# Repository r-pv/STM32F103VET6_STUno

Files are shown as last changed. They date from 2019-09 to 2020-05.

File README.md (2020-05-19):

# STM32F103VET6 STUno

An ST development board based on the STM32F103VET6/STM32F103VE (Clock: 72MHz, Flash: 512Kb, Ram:64Kb) MCU (the LQFP-100 version of the famous Blue Pill) compatible with STM32Duino (Arduino).

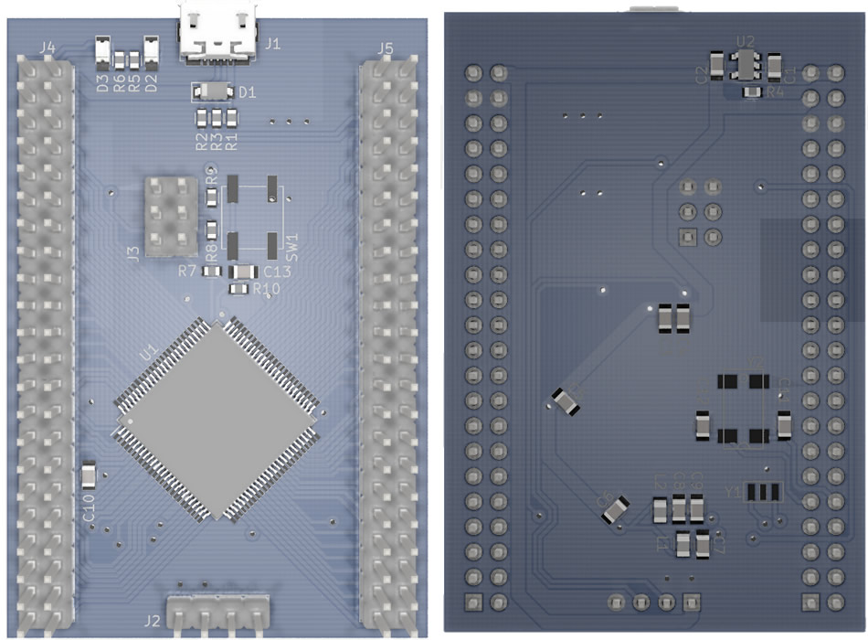
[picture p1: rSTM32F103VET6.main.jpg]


Pinout:

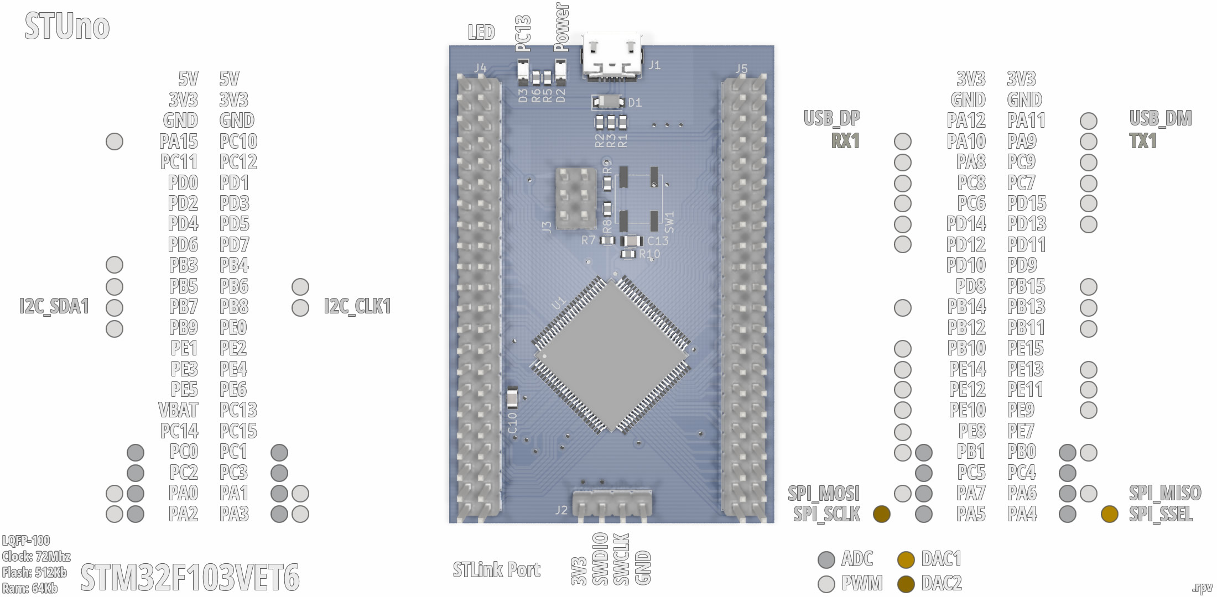
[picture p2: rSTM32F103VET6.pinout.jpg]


## Files and Folders description

- **RBOARD_F103VET6** it's the variant board for the STM32 Arduino Core.
- **rSTM32F103VET6** it's the KiCAD 5.1.2 project.
- **rSTM32F103VET6.schematic.pdf** the schematic.

## Install

**Update:** Since STCore version **1.9.0** most of the F103XXXX boards (including this) are already supported, so there is no need to install anything.

- This requires the [STM32 core for arduino](https://github.com/stm32duino/Arduino_Core_STM32/), the ST original.
- I used this [guide to add the board](https://github.com/stm32duino/wiki/wiki/Add-a-new-variant-(board)), you can check it or continue with my suggestions to install the new board.
- Copy the **"RBOARD_F103VET6"** folder to the Arduino **"variants"** folder, in win7 is located at: **c:\Users\\<USERNAME\>\AppData\Local\Arduino15\packages\STM32\hardware\stm32\1.8.0\variants**
- Edit the **"boards.txt"** file, in win7 is located at a lever up than the "variants" folder, search for the **Generic F1** board line and add the lines to leave it as I show you next:

```
GenF1.menu.pnum.Generic_F103RET6=Generic F103RET6 (Blue Button)
GenF1.menu.pnum.Generic_F103RET6.upload.maximum_size=524288
GenF1.menu.pnum.Generic_F103RET6.upload.maximum_data_size=65536
GenF1.menu.pnum.Generic_F103RET6.build.board=GENERIC_F103RET6
GenF1.menu.pnum.Generic_F103RET6.build.product_line=STM32F103xE
GenF1.menu.pnum.Generic_F103RET6.build.variant=Generic_F103Rx

# Generic STM32F103VET6 STUno
GenF1.menu.pnum.RBOARD_F103VET6=STM32F103VET6 STUno
GenF1.menu.pnum.RBOARD_F103VET6.upload.maximum_size=524288
GenF1.menu.pnum.RBOARD_F103VET6.upload.maximum_data_size=65536
GenF1.menu.pnum.RBOARD_F103VET6.build.board=RBOARD_F103VET6
GenF1.menu.pnum.RBOARD_F103VET6.build.product_line=STM32F103xE
GenF1.menu.pnum.RBOARD_F103VET6.build.variant=RBOARD_F103VET6
```
(add after the _"# Generic STM32F103Rx boards (Blue button)"_ section).

That's all.

So on the arduino IDE, on the **boards** menu pick the option _"Generic STM32F1 series"_ and the **board part number:** suboption pick the _"STM32F103VET6 STUno"_ option.

## The real board

**Front**

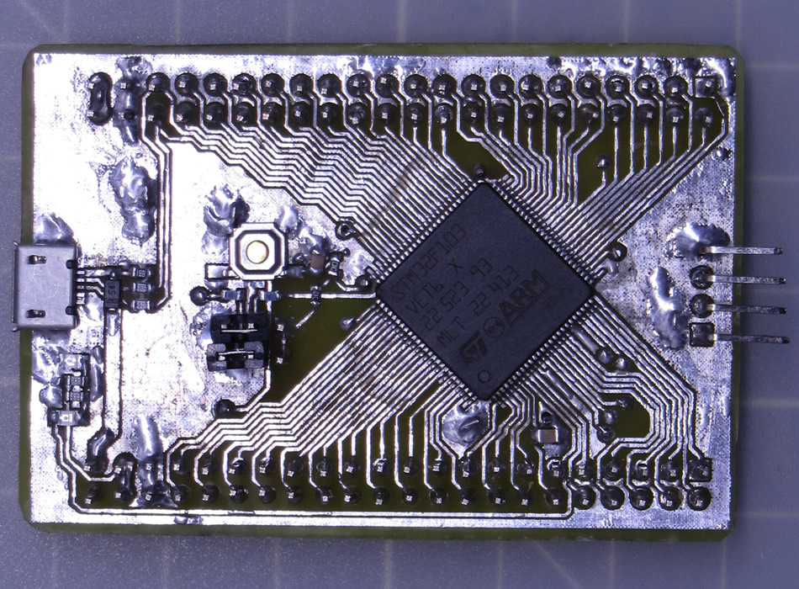
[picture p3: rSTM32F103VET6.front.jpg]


**Back**

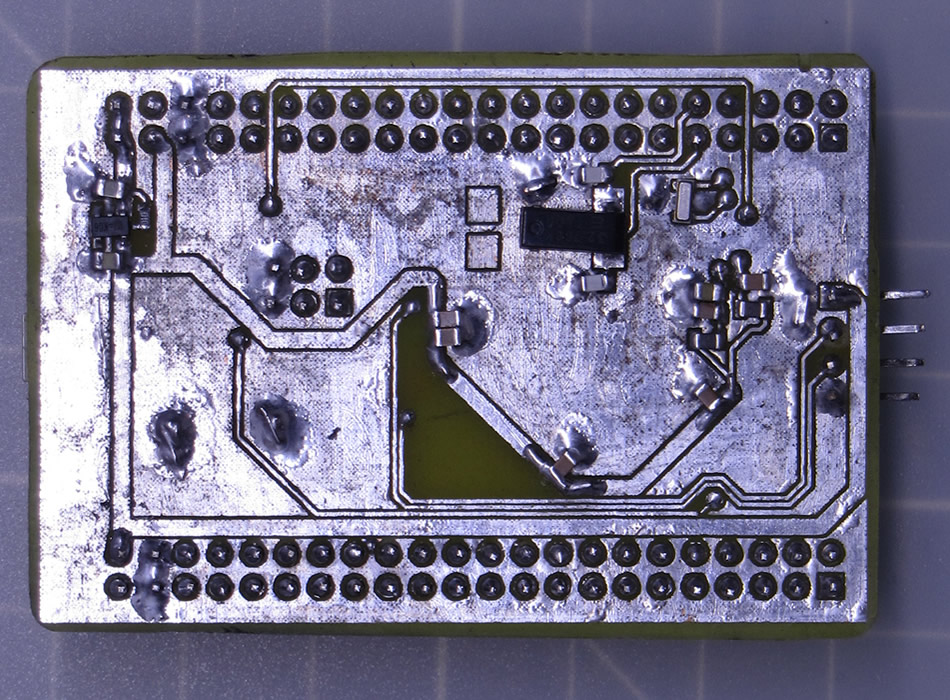
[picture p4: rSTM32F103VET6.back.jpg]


_*The footprint for the second crystal (Y2) was wrong on this board but it's already corrected on the KiCAD files._

## Running some tests

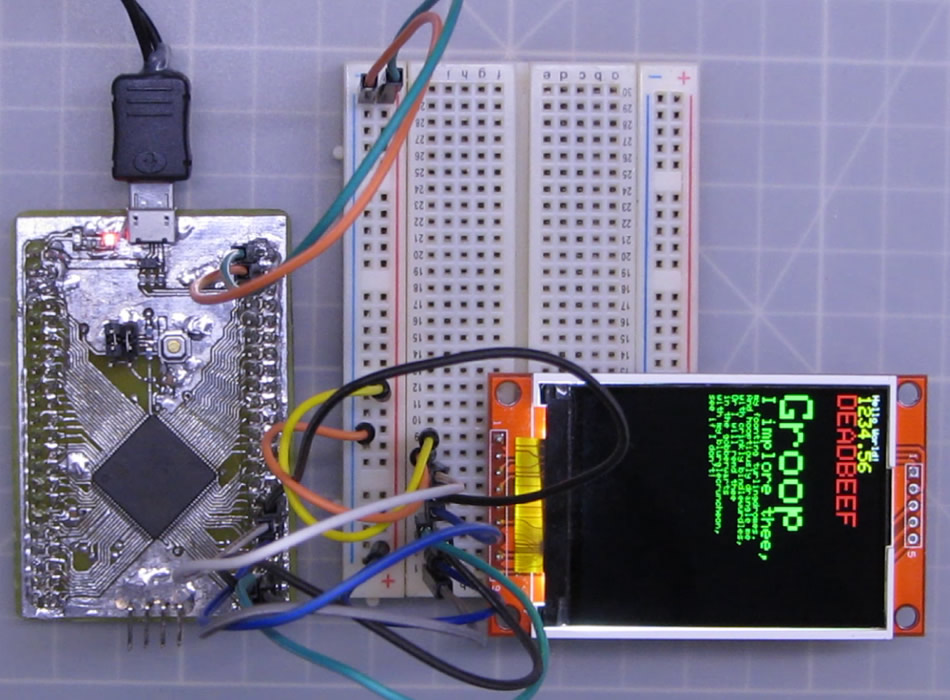
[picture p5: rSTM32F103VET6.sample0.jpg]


The **STUno** running the Adafruit ILI9341 library over hardware SPI.

_Video in progress..._

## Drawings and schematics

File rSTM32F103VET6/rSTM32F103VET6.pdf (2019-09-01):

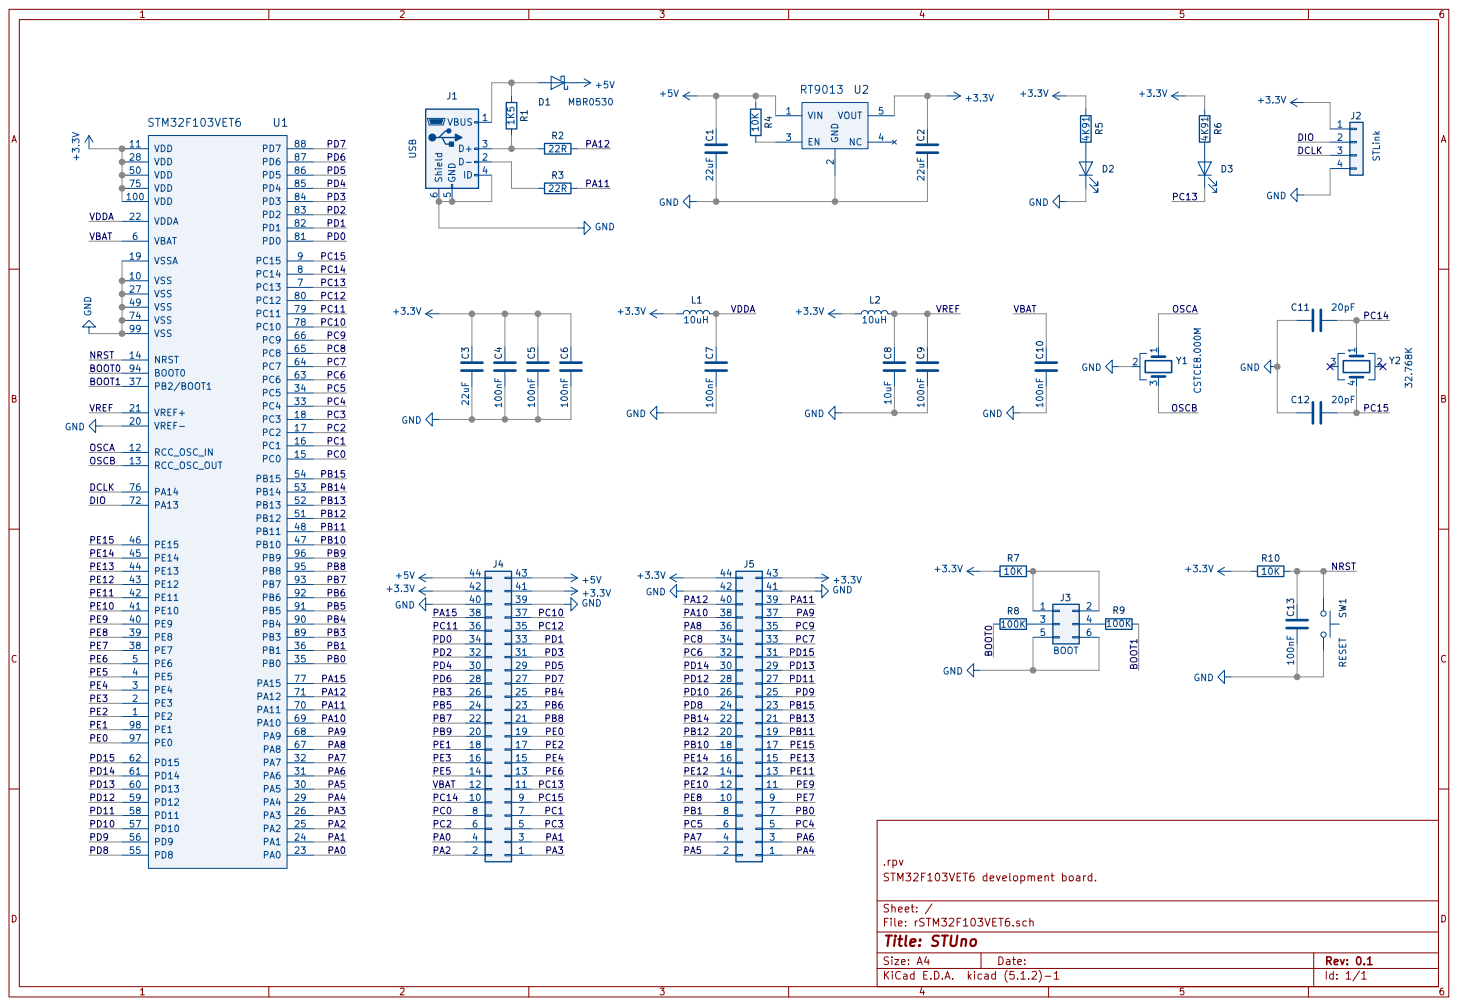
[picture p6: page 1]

File: rSTM32F103VET6.sch Sheet: / STM32F103VET6 development board.

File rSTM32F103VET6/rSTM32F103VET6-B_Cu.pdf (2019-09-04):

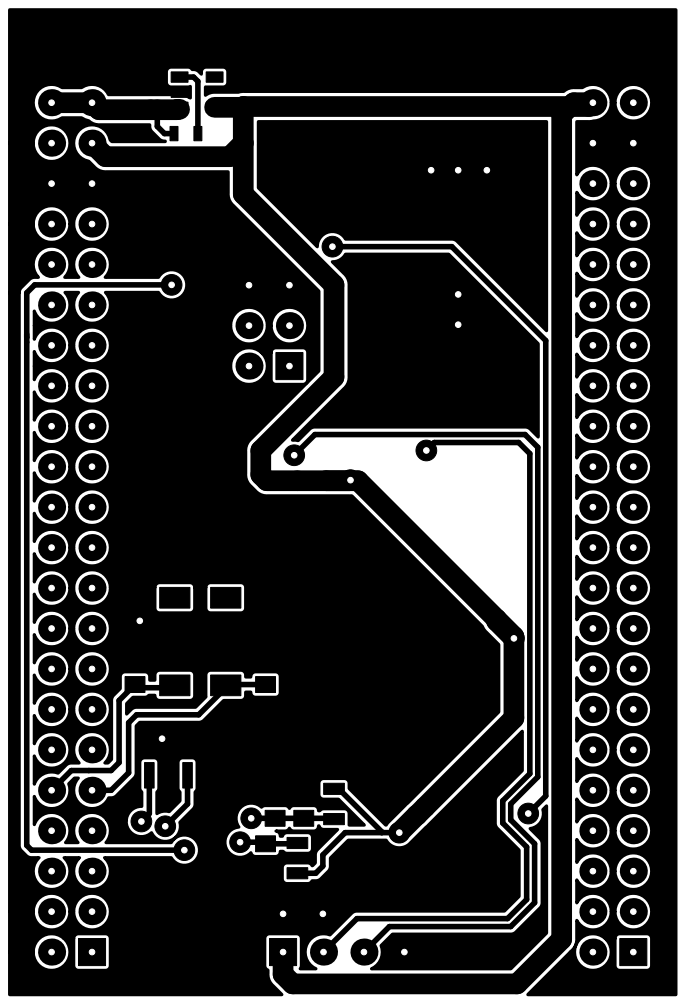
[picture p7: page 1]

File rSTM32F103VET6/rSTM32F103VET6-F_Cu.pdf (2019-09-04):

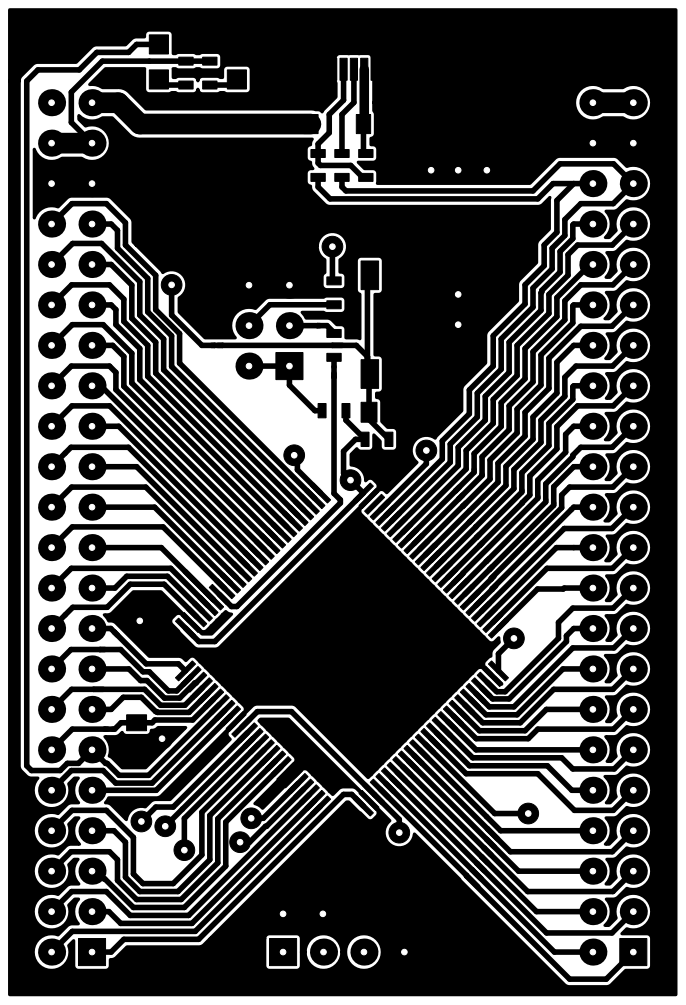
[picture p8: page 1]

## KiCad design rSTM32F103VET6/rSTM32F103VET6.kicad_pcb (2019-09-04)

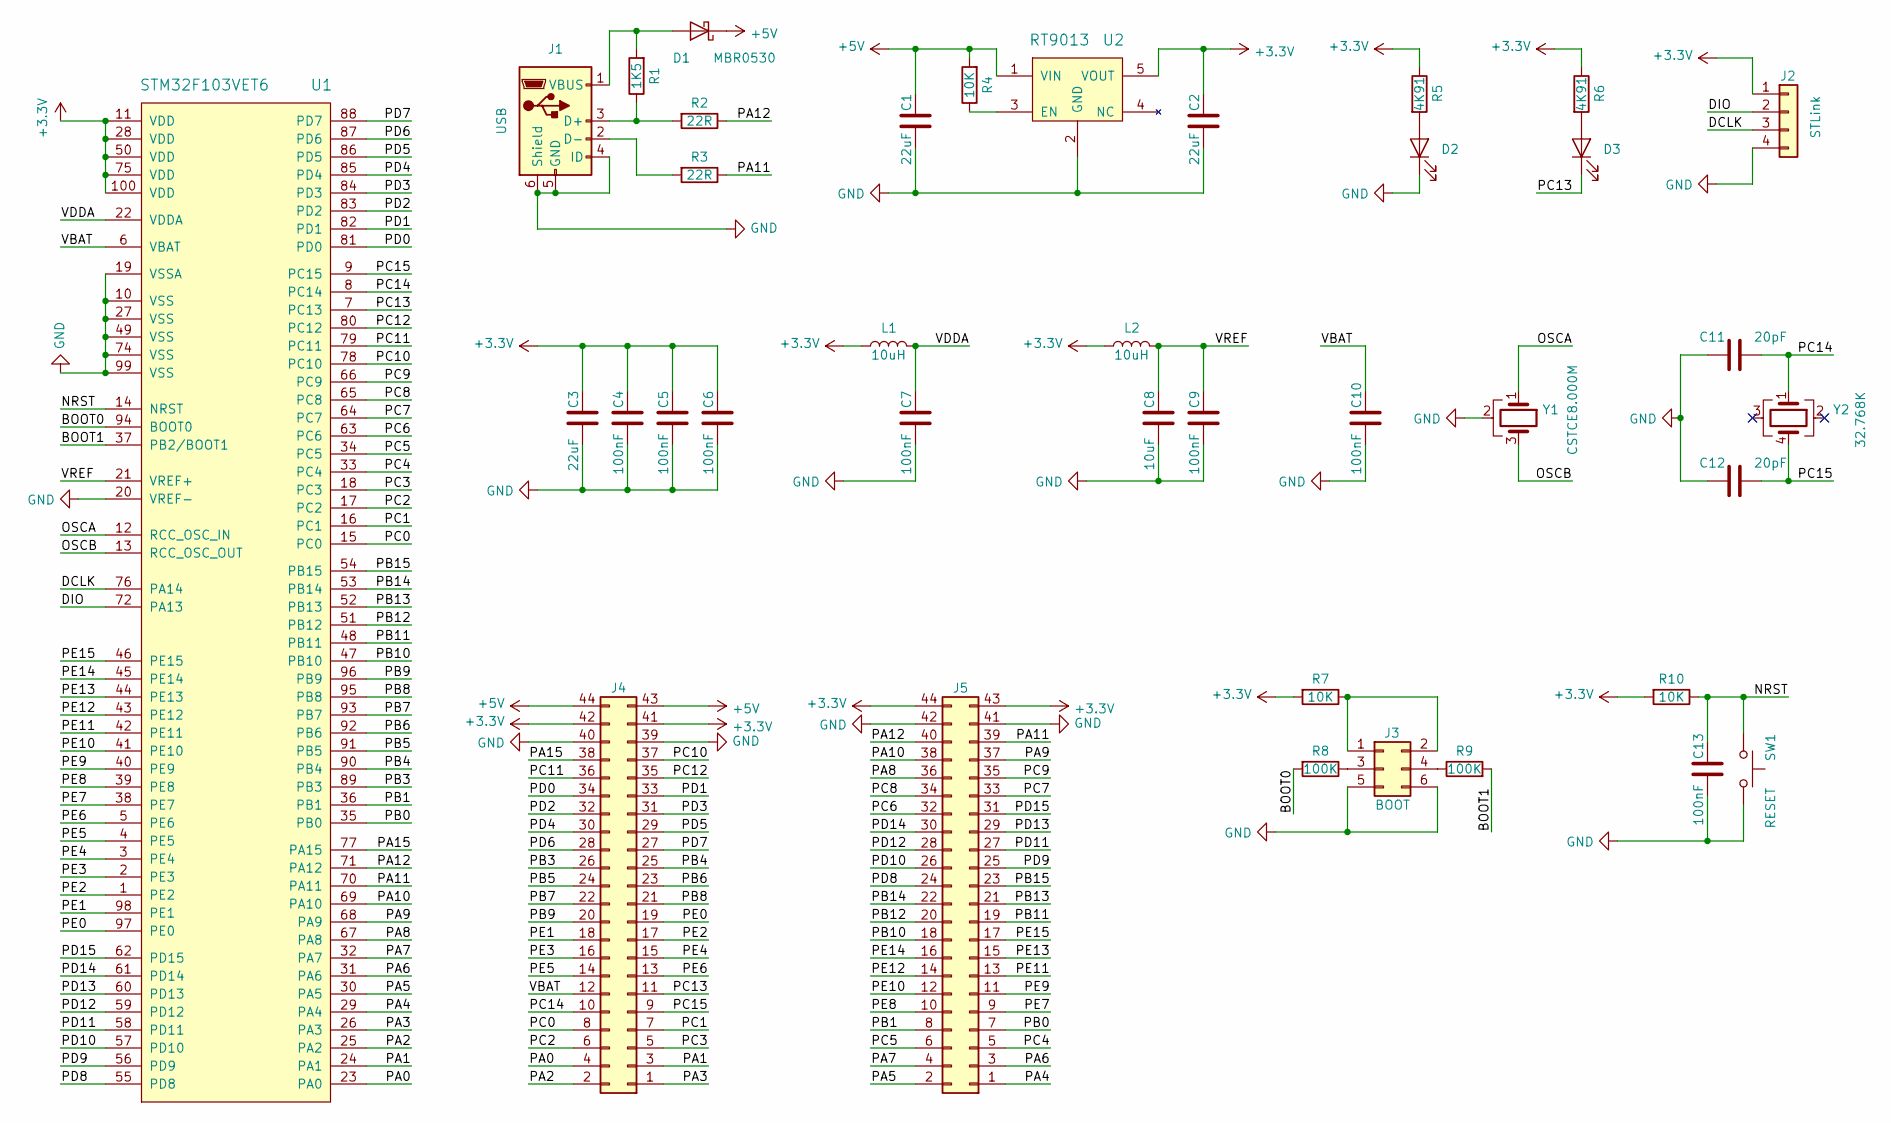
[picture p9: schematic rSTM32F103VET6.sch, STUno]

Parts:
C1, C2, C3: 22uF; C_0805
C4, C5, C6, C7, C9, C10, C13: 100nF; C_0805
C8: 10uF; C_0805
C11, C12: 20pF; C_0805
D1: MBR0530; D_SOD-123
D2, D3: LED; LED_0805
J1: USB; USB_Micro-B_Molex_47346-0001
J2: STLink; Pin_Header_Straight_1x04_Pitch2.54mm
J3: BOOT; Pin_Header_Straight_2x03_Pitch2.54mm
J4, J5: Pin_Header_Straight_2x22_Pitch2.54mm
L1, L2: 10uH; L_0805
R1: 1K5; R_0603
R2, R3: 22R; R_0603
R4, R7, R10: 10K; R_0603
R5, R6: 4K91; R_0603
R8, R9: 100K; R_0603
SW1: RESET; Switch_SMD_5.2x6.4_reset
U1: STM32F103VET6; LQFP-100_14x14mm_Pitch0.5mm
U2: RT9013; SOT-23-5
Y1: CSTCE8.000M; Crystal_CSTCE_3pin_3.2x1.3
Y2: 32.768K; Crystal_4pin_SMD_2.5x4.6

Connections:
+3V3: C2.1, C3.1, C4.1, C5.1, C6.1, J2.1, J4.41, J4.42, J5.43, J5.44, L1.1, L2.1, R5.1, R6.1, R7.2, R10.2, U1.11 (VDD), U1.28 (VDD), U1.50 (VDD), U1.75 (VDD), U1.100 (VDD), U2.5 (VOUT)
+5V: C1.1, D1.1 (K), J4.43, J4.44, R4.2, U2.1 (VIN)
/BOOT0: R8.2, U1.94 (BOOT0)
/BOOT1: R9.2, U1.37 (PB2/BOOT1)
/DCLK: J2.3, U1.76 (PA14)
/DIO: J2.2, U1.72 (PA13)
/NRST: C13.1, R10.1, SW1.1, U1.14 (NRST)
/OSCA: U1.12 (RCC_OSC_IN), Y1.1
/OSCB: U1.13 (RCC_OSC_OUT), Y1.3
/PA0: J4.4, U1.23 (PA0)
/PA1: J4.3, U1.24 (PA1)
/PA2: J4.2, U1.25 (PA2)
/PA3: J4.1, U1.26 (PA3)
/PA4: J5.1, U1.29 (PA4)
/PA5: J5.2, U1.30 (PA5)
/PA6: J5.3, U1.31 (PA6)
/PA7: J5.4, U1.32 (PA7)
/PA8: J5.36, U1.67 (PA8)
/PA9: J5.37, U1.68 (PA9)
/PA10: J5.38, U1.69 (PA10)
/PA11: J5.39, R3.1, U1.70 (PA11)
/PA12: J5.40, R2.1, U1.71 (PA12)
/PA15: J4.38, U1.77 (PA15)
/PB0: J5.7, U1.35 (PB0)
/PB1: J5.8, U1.36 (PB1)
/PB3: J4.26, U1.89 (PB3)
/PB4: J4.25, U1.90 (PB4)
/PB5: J4.24, U1.91 (PB5)
/PB6: J4.23, U1.92 (PB6)
/PB7: J4.22, U1.93 (PB7)
/PB8: J4.21, U1.95 (PB8)
/PB9: J4.20, U1.96 (PB9)
/PB10: J5.18, U1.47 (PB10)
/PB11: J5.19, U1.48 (PB11)
/PB12: J5.20, U1.51 (PB12)
/PB13: J5.21, U1.52 (PB13)
/PB14: J5.22, U1.53 (PB14)
/PB15: J5.23, U1.54 (PB15)
/PC0: J4.8, U1.15 (PC0)
/PC1: J4.7, U1.16 (PC1)
/PC2: J4.6, U1.17 (PC2)
/PC3: J4.5, U1.18 (PC3)
/PC4: J5.5, U1.33 (PC4)
/PC5: J5.6, U1.34 (PC5)
/PC6: J5.32, U1.63 (PC6)
/PC7: J5.33, U1.64 (PC7)
/PC8: J5.34, U1.65 (PC8)
/PC9: J5.35, U1.66 (PC9)
/PC10: J4.37, U1.78 (PC10)
/PC11: J4.36, U1.79 (PC11)
/PC12: J4.35, U1.80 (PC12)
/PC13: D3.1 (K), J4.11, U1.7 (PC13)
/PC14: C11.1, J4.10, U1.8 (PC14), Y2.1
/PC15: C12.1, J4.9, U1.9 (PC15), Y2.4
/PD0: J4.34, U1.81 (PD0)
/PD1: J4.33, U1.82 (PD1)
/PD2: J4.32, U1.83 (PD2)
/PD3: J4.31, U1.84 (PD3)
/PD4: J4.30, U1.85 (PD4)
/PD5: J4.29, U1.86 (PD5)
/PD6: J4.28, U1.87 (PD6)
/PD7: J4.27, U1.88 (PD7)
/PD8: J5.24, U1.55 (PD8)
/PD9: J5.25, U1.56 (PD9)
/PD10: J5.26, U1.57 (PD10)
/PD11: J5.27, U1.58 (PD11)
/PD12: J5.28, U1.59 (PD12)
/PD13: J5.29, U1.60 (PD13)
/PD14: J5.30, U1.61 (PD14)
/PD15: J5.31, U1.62 (PD15)
/PE0: J4.19, U1.97 (PE0)
/PE1: J4.18, U1.98 (PE1)
/PE2: J4.17, U1.1 (PE2)
/PE3: J4.16, U1.2 (PE3)
/PE4: J4.15, U1.3 (PE4)
/PE5: J4.14, U1.4 (PE5)
/PE6: J4.13, U1.5 (PE6)
/PE7: J5.9, U1.38 (PE7)
/PE8: J5.10, U1.39 (PE8)
/PE9: J5.11, U1.40 (PE9)
/PE10: J5.12, U1.41 (PE10)
/PE11: J5.13, U1.42 (PE11)
/PE12: J5.14, U1.43 (PE12)
/PE13: J5.15, U1.44 (PE13)
/PE14: J5.16, U1.45 (PE14)
/PE15: J5.17, U1.46 (PE15)
/VBAT: C10.1, J4.12, U1.6 (VBAT)
/VDDA: C7.1, L1.2, U1.22 (VDDA)
/VREF: C8.1, C9.1, L2.2, U1.21 (VREF+)
GND: C1.2, C2.2, C3.2, C4.2, C5.2, C6.2, C7.2, C8.2, C9.2, C10.2, C11.2, C12.2, C13.2, D2.1 (K), J1.4 (ID), J1.5 (GND), J1.6 (Shield), J2.4, J3.5, J3.6, J4.39, J4.40, J5.41, J5.42, SW1.2, U1.10 (VSS), U1.19 (VSSA), U1.20 (VREF-), U1.27 (VSS), U1.49 (VSS), U1.74 (VSS), U1.99 (VSS), U2.2 (GND), Y1.2
unnamed: D1.2 (A), J1.1 (VBUS), R1.2
unnamed: D2.2 (A), R5.2
unnamed: D3.2 (A), R6.2
unnamed: J1.2 (D-), R3.2
unnamed: J1.3 (D+), R1.1, R2.2
unnamed: J3.1, J3.2, R7.1
unnamed: J3.3, R8.1
unnamed: J3.4, R9.1
unnamed: R4.1, U2.3 (EN)

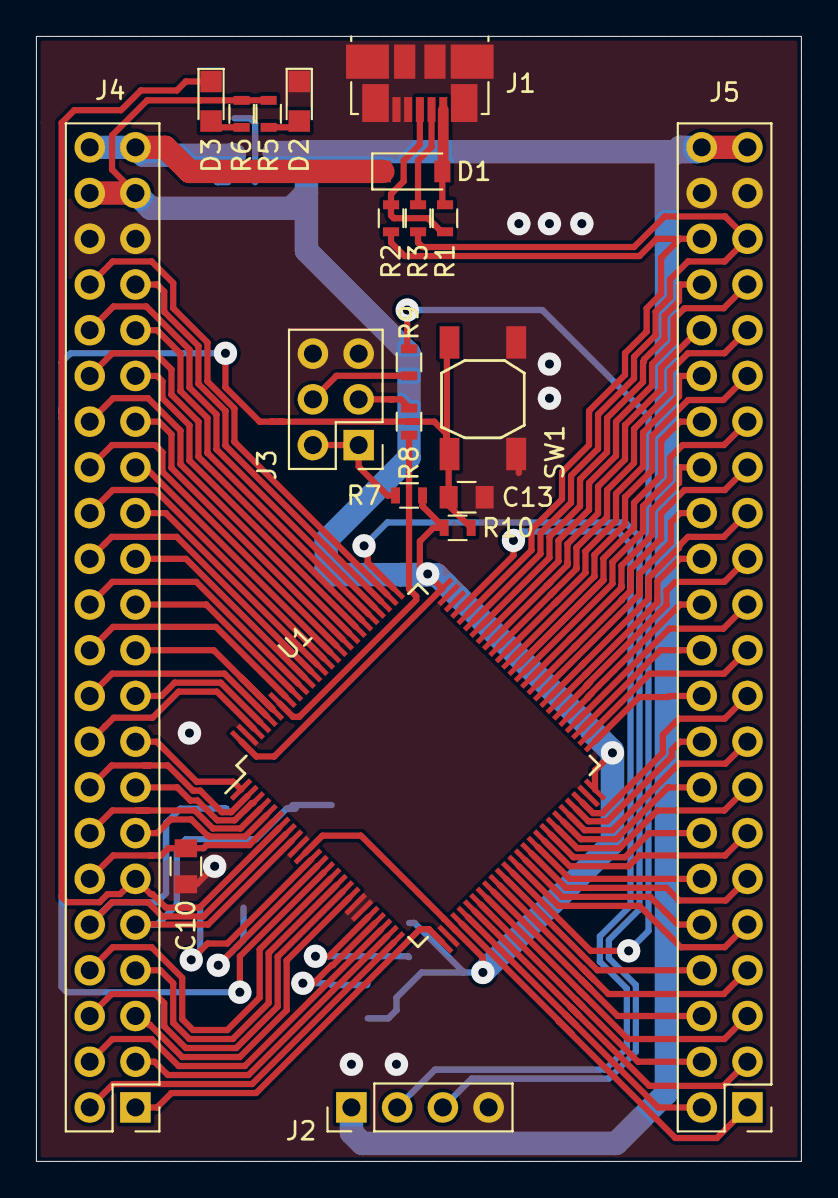
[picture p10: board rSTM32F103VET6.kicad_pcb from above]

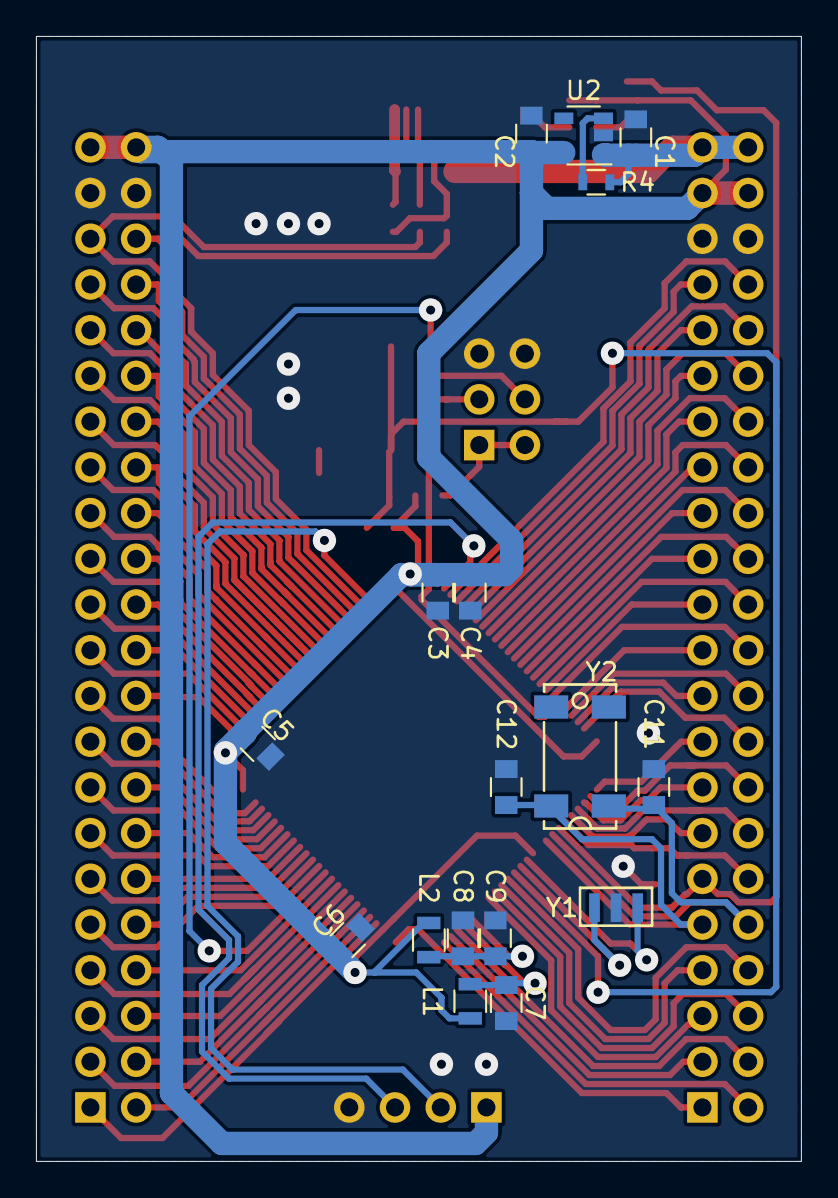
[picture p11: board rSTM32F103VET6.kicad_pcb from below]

Board: 2 copper layers, 42.5 x 62.5 mm, 38 parts (17 on the bottom side), 99 nets.

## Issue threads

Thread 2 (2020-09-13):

Example

saeed14473, 2020-09-13:
Can you please give us some example code with arduino ide?

r-pv, 2020-09-13:
Hi, I'm afraid that I don't understand the question, what kind of example do you want?, this will run most of the arduino standard code and libraries, almost like an arduino uno.

saeed14473, 2020-09-14:
Let me ask a better question, stm32f103VE has a lot of timer, interrupt, DAC, CAN and ... right?
Can we use all of its features with Arduino IDE?

r-pv, 2020-09-14:
Hi, yes, all the hardware works (inherited from the ST core), regarding the examples you can check the official core API (PWM, I2C, SPI, serial documentation):

https://github.com/stm32duino/wiki/wiki/API

and the examples (this it's a separate installation from the core, it should be available on the libraries manager on the arduino IDE):

https://github.com/stm32duino/STM32Examples

includes examples: PWM, interrupts, timers and a few others.

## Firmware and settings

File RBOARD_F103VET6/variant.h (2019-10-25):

/*
 *******************************************************************************
 * Copyright (c) 2017, STMicroelectronics
 * All rights reserved.
 *
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
 * THIS SOFTWARE IS PROVIDED BY THE COPYRIGHT HOLDERS AND CONTRIBUTORS "AS IS"
 * AND ANY EXPRESS OR IMPLIED WARRANTIES, INCLUDING, BUT NOT LIMITED TO, THE
 * IMPLIED WARRANTIES OF MERCHANTABILITY AND FITNESS FOR A PARTICULAR PURPOSE ARE
 * DISCLAIMED. IN NO EVENT SHALL THE COPYRIGHT HOLDER OR CONTRIBUTORS BE LIABLE
 * FOR ANY DIRECT, INDIRECT, INCIDENTAL, SPECIAL, EXEMPLARY, OR CONSEQUENTIAL
 * DAMAGES (INCLUDING, BUT NOT LIMITED TO, PROCUREMENT OF SUBSTITUTE GOODS OR
 * SERVICES; LOSS OF USE, DATA, OR PROFITS; OR BUSINESS INTERRUPTION) HOWEVER
 * CAUSED AND ON ANY THEORY OF LIABILITY, WHETHER IN CONTRACT, STRICT LIABILITY,
 * OR TORT (INCLUDING NEGLIGENCE OR OTHERWISE) ARISING IN ANY WAY OUT OF THE USE
 * OF THIS SOFTWARE, EVEN IF ADVISED OF THE POSSIBILITY OF SUCH DAMAGE.
 *******************************************************************************
 */
#ifndef _VARIANT_ARDUINO_STM32_
#define _VARIANT_ARDUINO_STM32_

/*----------------------------------------------------------------------------
 *        Headers
 *----------------------------------------------------------------------------*/
#ifdef __cplusplus
extern "C"{
#endif // __cplusplus

/*----------------------------------------------------------------------------
 *        Pins
 *----------------------------------------------------------------------------*/
// USB connector on the top, MCU side
// Left.Side
#define PA15  0
#define PC10  1
#define PC11  2
#define PC12  3
#define PD0   4
#define PD1   5
#define PD2   6
#define PD3   7
#define PD4   8
#define PD5   9
#define PD6   10
#define PD7   11
#define PB3   12
#define PB4   13
#define PB5   14
#define PB6   15
#define PB7   16
#define PB8   17
#define PB9   18
#define PE0   19
#define PE1   20
#define PE2   21
#define PE3   22
#define PE4   23
#define PE5   24
#define PE6   25
/*				 VBAT */
#define PC13  26
#define PC14  27
#define PC15  28
#define PC0   29
#define PC1   30
#define PC2   31
#define PC3   32
#define PA0   33
#define PA1   34
#define PA2   35
#define PA3   36
// Bottom.side
#define PA13  37 //D10   - SWDIO
#define PA14  38 //D11   - SWCLK
// Right.side
#define PA4   39
#define PA5   40
#define PA6   41
#define PA7   42
#define PC4   43
#define PC5   44
#define PB0   45
#define PB1   46
#define PE7   47
#define PE8   48
#define PE9   49
#define PE10  50
#define PE11  51
#define PE12  52
#define PE13  53
#define PE14  54
#define PE15  55
#define PB10  56
#define PB11  57
#define PB12  58
#define PB13  59
#define PB14  60
#define PB15  61
#define PD8   62
#define PD9   63
#define PD10  64
#define PD11  65
#define PD12  66
#define PD13  67
#define PD14  68
#define PD15  69
#define PC6   70
#define PC7   71
#define PC8   72
#define PC9   73
#define PA8   74
#define PA9   75
#define PA10  76
#define PA11  77
#define PA12  78

// Define pin names to match digital pin number --> Dx
// It could be used with preprocessor tests (e.g. #if PXn == 3)
// so an enum will not work.
// !!!
// !!! Copy the digitalPin[] array from the variant.cpp
// !!! and remove all '_': PX_n --> PXn
// !!! For NC, comment the line to warn x pin number is NC
// !!! // x is NC
// !!! For duplicated pin name, comment the line to warn x pin number
// !!! is PXn which is already defined with y pin number
// !!! // x is PXn (y)
// !!! Ex:
// !!! ...
// !!! #define PA4  20 // A14
// !!! #define PB4  21
// !!! #define PB5  22
// !!! #define PB3  23
// !!! // 24 is PA4 (20)
// !!! // 25 is PB4 (21)
// !!! #define PA2  26 // A15
// !!! ...
//#define PXn x

// This must be a literal
// It is used with preprocessor tests (e.g. #if NUM_DIGITAL_PINS > 3)
// so an enum will not work.
#define NUM_DIGITAL_PINS        96

// Allow to define Arduino style alias for analog input pin number --> Ax
// All pins are digital, analog inputs are a subset of digital pins
// and must be contiguous to be able to loop on each value
// This must be a literal with a value less than or equal to MAX_ANALOG_INPUTS
// defined in pin_arduino.h
// It is used with preprocessor tests (e.g. #if NUM_ANALOG_INPUTS > 3)
// so an enum will not work.
// !!!
// !!! It must be aligned with the number of analog PinName
// !!! defined in digitalPin[] array in variant.cpp
// !!!
#define NUM_ANALOG_INPUTS       16
// Define digital pin number of the first analog input  (i.e. which digital pin is A0)
// First analog pin value (A0) must be greater than or equal to NUM_ANALOG_INPUTS
#define NUM_ANALOG_FIRST        79

// Below ADC, DAC and PWM definitions already done in the core
// Could be redefined here if needed
// ADC resolution is 12bits
//#define ADC_RESOLUTION          12
//#define DACC_RESOLUTION         12

// PWM resolution
//#define PWM_RESOLUTION          8
//#define PWM_FREQUENCY           1000
//#define PWM_MAX_DUTY_CYCLE      255

// On-board LED pin number
#define LED_BUILTIN             PC13
#define LED_GREEN               LED_BUILTIN

// On-board user button
#define USER_BTN                x

// Below SPI and I2C definitions already done in the core
// Could be redefined here if differs from the default one
// SPI Definitions
// SPI Definitions
#define PIN_SPI_SS              PA4
#define PIN_SPI_MOSI            PA7
#define PIN_SPI_MISO            PA6
#define PIN_SPI_SCK             PA5

// I2C Definitions
#define PIN_WIRE_SDA            PB7 // Default for Arduino connector compatibility
#define PIN_WIRE_SCL            PB6  // Default for Arduino connector compatibility

// Timer Definitions
// Do not use timer used by PWM pins when possible. See PinMap_PWM.
#define TIMER_TONE              TIM3

// Do not use basic timer: OC is required
#define TIMER_SERVO             TIM2  //TODO: advanced-control timers don't work

// UART Definitions
#define SERIAL_UART_INSTANCE    1
// Default pin used for 'Serial' instance
// Mandatory for Firmata
#define PIN_SERIAL_RX           PA10
#define PIN_SERIAL_TX           PA9

// UART Definitions
// Define here Serial instance number to map on Serial generic name
//#define SERIAL_UART_INSTANCE    x //ex: 2 for Serial2 (USART2)
// DEBUG_UART could be redefined to print on another instance than 'Serial'
//#define DEBUG_UART              ((USART_TypeDef *) U(S)ARTX) // ex: USART3
// DEBUG_UART baudrate, default: 9600 if not defined
//#define DEBUG_UART_BAUDRATE     x
// DEBUG_UART Tx pin name, default: the first one found in PinMap_UART_TX for DEBUG_UART
//#define DEBUG_PINNAME_TX        PX_n // PinName used for TX
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

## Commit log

2019-09-01 KiCAD project.
    [rSTM32F103VET6.kicad_pcb, rSTM32F103VET6.sch]
2019-09-04 KiCAD Project.
    Footprint fix.
    [rSTM32F103VET6.kicad_pcb, rSTM32F103VET6.sch]
2019-10-25 Pinout updated: added ADC and PWM pins.
2019-10-25 Fixed a bug with the analogs.
    Fixed a mistake I made.
    [variant.cpp, variant.h]
